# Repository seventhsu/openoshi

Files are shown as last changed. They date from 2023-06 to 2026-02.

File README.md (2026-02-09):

# OpenOshi
A fully open-source, DIY concert penlight. (v2.0)

Whether in the midst of the crowd at Belluna Dome or sitting in the dark in your bedroom, cheer on your favorite idols with this powerful, fully customizable penlight. It runs off of a single lithium battery and charges via USB-C to shine bright for hours of your favorite performances.

Best of all, it costs **less than $10 to make!** Total! That includes the PCB, the components, the battery, and the handle and tube! All while being fully hackable and modifiable. Manufacture in quantity and see how many you can hold in one hand: a classic idolfan challenge. 

This project consists of:
- a 3D-printable handle and screw-in translucent blade
- the Lightboard: a central PCB with an RGBW LED, a CH32V003F4U6 microcontroller, buttons and a USB-C charging port
- software to easily add your favorite idols' colors to your Lightboard

OpenOshi's electrical and mechanical components are open-source hardware licensed under CERN-OHL-S-2.0 (see the root `LICENSE` file). The firmware is open-source software licensed under the MIT License (see `firmware/LICENSE`). The `ch32fun` SDK included as a submodule of the firmware remains under its own MIT License; refer to the submodule's `LICENSE` file.

**Building tips**
- For printing the handle, I suggest a neutral color of PLA filament, and for the tube, transparent PETG printed at 100% rectilinear infill.
- The PCB is made to JLCPCB 2-layer specifications and tolerances as of July 2025. Modify if needed to meet your preferred PCB supplier's capabilities.
- The control firmware can be flashed to the board with a single wire using the SWIO programming pad on the top. To do so, you will need a WCH-Link programmer or equivalent and a flashing tool; [`ch32fun`](https://github.com/cnlohr/ch32fun) names several good open-source options like the `esp32s2-funprog` for the former, and it implements the `minichlink` tool for the latter.

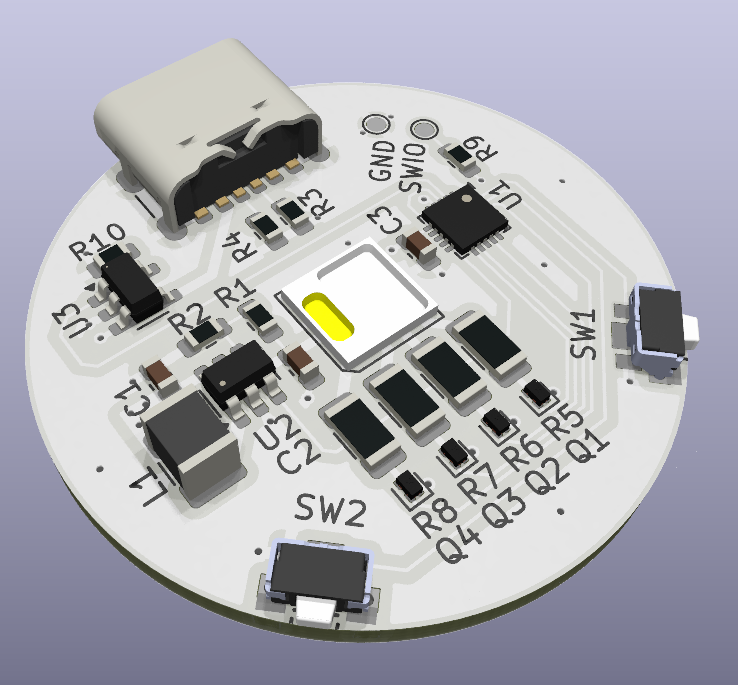
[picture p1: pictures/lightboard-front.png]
Lightboard top side

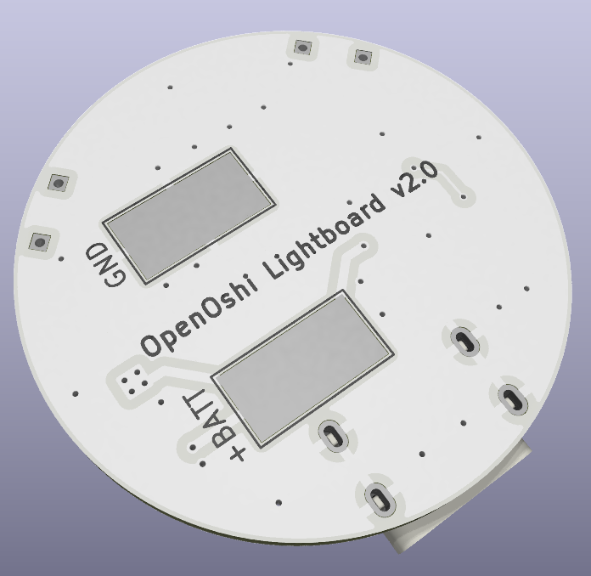
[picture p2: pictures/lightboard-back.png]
Lightboard bottom side


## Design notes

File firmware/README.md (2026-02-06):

# OpenOshi CH32V003 firmware

To pull the `ch32fun` SDK and compile `minichlink`, the flasher tool:
```bash
git submodule update --init --recursive
cd ch32fun/minichlink
make
```

To build the board firmware, creating images and build artifacts in `src/`:
```bash
make -C src
```

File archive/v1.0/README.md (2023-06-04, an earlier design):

# OpenOshi
A fully open-source, DIY idol concert lightstick. (v1.0)

Whether in the midst of the crowd at Belluna Dome or sitting in the dark in your bedroom, cheer on your favorite idols with this powerful, fully customizable lightstick. Designed in the image of the King Blade X10, ubiquitous in Japan, this lightstick runs off of a single lithium-ion battery to shine bright for hours of your favorite performances.

OpenOshi is fully DIY. It consists of:
- a 3D-printable handle and screw-in translucent blade
- a central PCB with an RGBW LED
- a simple board programming interface to add your favorite idols' colors

OpenOshi is open-source; all are free to modify it to their liking or submit improvements.

**Building tips**
- For the handle and cap, I suggest a neutral color of PLA filament, and for the tube, transparent PETG printed at 100% rectilinear infill.
- The PCB is made to OSH Park specifications and tolerances as of June 2023. Modify as needed to meet your preferred PCB supplier's capabilities.
- Control software written in AVR C is provided, and can be compiled and flashed to the board using the 6-pin ICSP port at the bottom.
- The handle was originally designed with a single lithium-ion battery as a power source in mind, so there is a cutout in the bottom of the handle for a common TP4056 USB-C lithium-ion charger. However, the board can also be powered by three alkaline batteries (such as AAAs) in series for 4.5V, so the cutout can be patched up if deemed unnecessary.




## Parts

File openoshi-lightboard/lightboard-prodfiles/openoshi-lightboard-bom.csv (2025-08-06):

Comment | Designator | Footprint | LCSC Part Number
10u | C1,C2 | Capacitor_SMD:C_0603_1608Metric | C19702
0.1u | C3 | Capacitor_SMD:C_0603_1608Metric | C14663
USB_C_Receptacle_PowerOnly_6P | J1 | Connector_USB:USB_C_Receptacle_GCT_USB4125-xx-x_6P_TopMnt_Horizontal | C456012
4.7uH | L1 | Inductor_SMD:L_1210_3225Metric | C703083
PMZ600UNE | Q1,Q2,Q3,Q4 | Package_TO_SOT_SMD:SOT-883 | C547286
1Meg | R1 | Resistor_SMD:R_0603_1608Metric | C105578
127K | R2 | Resistor_SMD:R_0603_1608Metric | C245905
5.1K | R3,R4 | Resistor_SMD:R_0603_1608Metric | C105580
12.7 | R5,R8 | Resistor_SMD:R_1206_3216Metric | C870404
20 | R6 | Resistor_SMD:R_1206_3216Metric | C114941
11.3 | R7 | Resistor_SMD:R_1206_3216Metric | C870385
220 | R9 | Resistor_SMD:R_0603_1608Metric | C107696
2K | R10 | Resistor_SMD:R_0603_1608Metric | C105576
AKE31A | SW1,SW2 | openoshi-lightboard:SW_EVP-AKE31A_PAN | C569760
CH32V003FxUx | U1 | Package_DFN_QFN:QFN-20-1EP_3x3mm_P0.4mm_EP1.65x1.65mm | C5299908
TLV61070A | U2 | Package_TO_SOT_SMD:SOT-23-6 | C6881375
TP4054 | U3 | Package_TO_SOT_SMD:SOT-23-5 | C668215

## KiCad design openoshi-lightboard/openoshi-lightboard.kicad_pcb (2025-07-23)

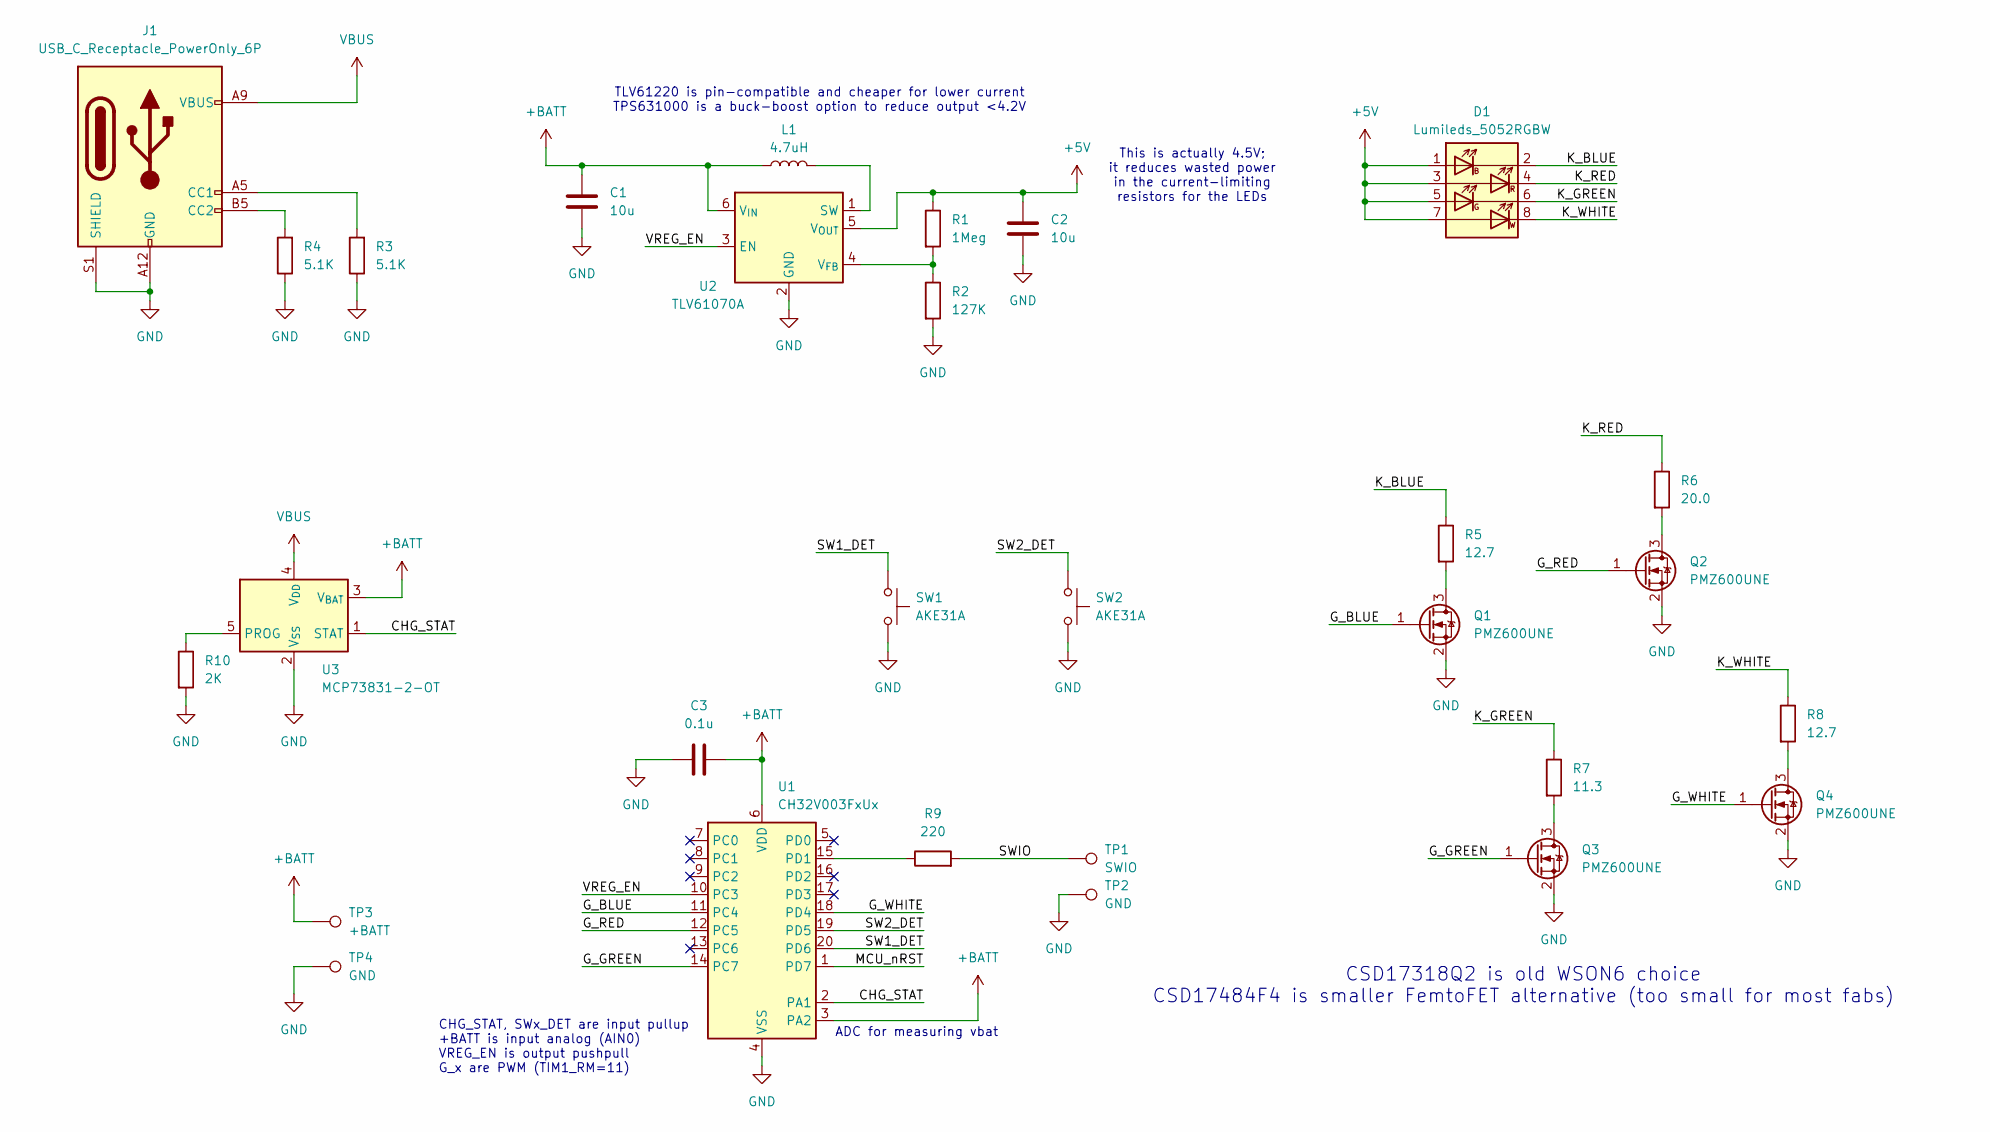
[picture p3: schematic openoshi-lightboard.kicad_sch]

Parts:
C1, C2: 10u; C_0603_1608Metric
C3: 0.1u; C_0603_1608Metric
D1: Lumileds_5052RGBW; LED_Lumileds_5052RGBW_LGA9_5.0x5.2mm_P0.5mm
J1: USB_C_Receptacle_PowerOnly_6P; USB_C_Receptacle_GCT_USB4125-xx-x_6P_TopMnt_Horizontal
L1: 4.7uH; L_1210_3225Metric
Q1, Q2, Q3, Q4: PMZ600UNE; SOT-883
R1: 1Meg; R_0603_1608Metric
R2: 127K; R_0603_1608Metric
R3, R4: 5.1K; R_0603_1608Metric
R5, R8: 12.7; R_1206_3216Metric
R6: 20.0; R_1206_3216Metric
R7: 11.3; R_1206_3216Metric
R9: 220; R_0603_1608Metric
R10: 2K; R_0603_1608Metric
SW1, SW2: AKE31A; SW_EVP-AKE31A_PAN
TP1: SWIO; TestPoint_Pad_D1.0mm
TP2: GND; TestPoint_Pad_D1.0mm
TP3: +BATT; Battery_SolderPad
TP4: GND; Battery_SolderPad
U1: CH32V003FxUx; QFN-20-1EP_3x3mm_P0.4mm_EP1.65x1.65mm
U2: TLV61070A; SOT-23-6
U3: MCP73831-2-OT; SOT-23-5

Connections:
+5V: C2.1, D1.1 (AB), D1.3 (AR), D1.5 (AG), D1.7 (AW), D1.9 (AR), R1.1, U2.5 (V_{OUT})
+BATT: C1.1, C3.2, L1.1, TP3.1, U1.3 (PA2), U1.6 (VDD), U2.6 (V_{IN}), U3.3 (V_{BAT})
/CHG_STAT: U1.2 (PA1), U3.1 (STAT)
/G_BLUE: Q1.1 (G), U1.11 (PC4)
/G_GREEN: Q3.1 (G), U1.14 (PC7)
/G_RED: Q2.1 (G), U1.12 (PC5)
/G_WHITE: Q4.1 (G), U1.18 (PD4)
/K_BLUE: D1.2 (KB), R5.1
/K_GREEN: D1.6 (KG), R7.1
/K_RED: D1.4 (KR), R6.1
/K_WHITE: D1.8 (KW), R8.1
/MCU_nRST: U1.1 (PD7)
/SW1_DET: SW1.1, U1.20 (PD6)
/SW2_DET: SW2.1, U1.19 (PD5)
/SWIO: R9.2, TP1.1
/VREG_EN: U1.10 (PC3), U2.3 (EN)
GND: C1.2, C2.2, C3.1, J1.A12 (GND), J1.B12 (GND), J1.S1 (SHIELD), Q1.2 (S), Q2.2 (S), Q3.2 (S), Q4.2 (S), R2.2, R3.1, R4.1, R10.2, SW1.2, SW2.2, TP2.1, TP4.1, U1.4 (VSS), U1.21 (VSS), U2.2 (GND), U3.2 (V_{SS})
unnamed: J1.A5 (CC1), R3.2
unnamed: J1.B5 (CC2), R4.2
unnamed: Q1.3 (D), R5.2
unnamed: Q2.3 (D), R6.2
unnamed: Q3.3 (D), R7.2
unnamed: Q4.3 (D), R8.2
unnamed: R9.1, U1.15 (PD1)
unnamed: L1.2, U2.1 (SW)
unnamed: R1.2, R2.1, U2.4 (V_{FB})
unnamed: R10.1, U3.5 (PROG)
VBUS: J1.A9 (VBUS), J1.B9 (VBUS), U3.4 (V_{DD})

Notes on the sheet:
This is actually 4.5V; it reduces wasted power in the current-limiting resistors for the LEDs
CSD17318Q2 is old WSON6 choice CSD17484F4 is smaller FemtoFET alternative (too small for most fabs)
TLV61220 is pin-compatible and cheaper for lower current TPS631000 is a buck-boost option to reduce output <4.2V
CHG_STAT, SWx_DET are input pullup +BATT is input analog (AIN0) VREG_EN is output pushpull G_x are PWM (TIM1_RM=11)
ADC for measuring vbat

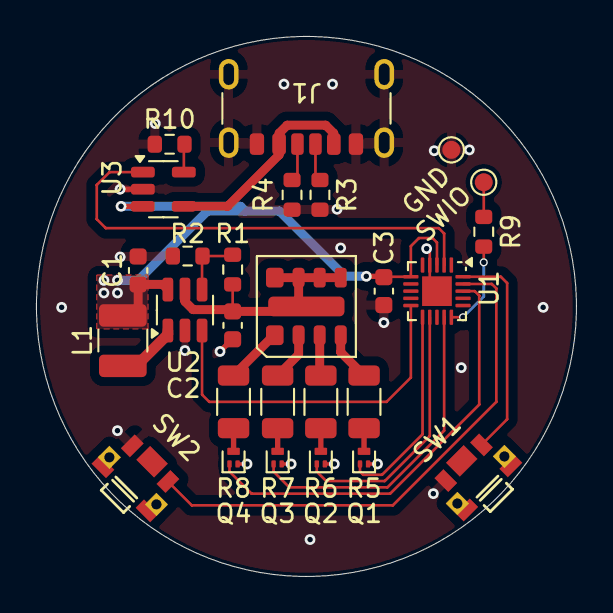
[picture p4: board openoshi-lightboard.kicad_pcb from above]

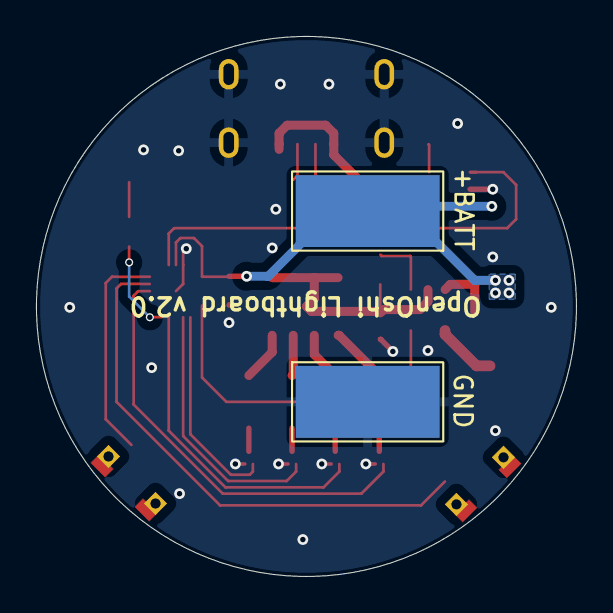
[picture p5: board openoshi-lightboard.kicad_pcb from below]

Board: 2 copper layers, 30.0 x 30.0 mm, 29 parts (2 on the bottom side), 27 nets.

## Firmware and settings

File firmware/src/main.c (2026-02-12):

// SPDX-License-Identifier: MIT
// Copyright (c) 2025-2026 Seventhsu

#include "../ch32fun/ch32fun/ch32fun.h"
#include <stdio.h>

#define PERIPH_CLOCK FUNCONF_SYSTEM_CORE_CLOCK  // HPRE=DIV1 after SystemInit

#define LED_PWM_MAX_FREQ_HZ 1000 // Change me at your leisure!
#define COLOR_BIT_DEPTH 8

#define NUM_COLORS     (sizeof(colorTable) / sizeof(colorTable[0]))
#define DEBOUNCE_MS    30
#define LONG_PRESS_MS  800
#define POLL_MS        10

// colorTable[i][0:3] represent B, G, R, W channels of one color setting
uint8_t colorTable[][4] = {
	{0x0,	0x0,	0xff,	0x0},   // Color red
    {0x0,	0xff,	0xff,	0x0},   // Color yellow
	{0x0,	0xff,	0x0,	0x0},   // Color green
    {0xff,	0xff,	0x0,	0x0},   // Color cyan
	{0xff,	0x0,	0x0,	0x0},   // Color blue
    {0xff,	0x0,	0xff,	0x0},   // Color magenta
	{0x0,	0x0,	0x0,	0xff},  // Color white
};

// The color the penlight should display if it was on (index into colorTable)
static volatile int currColor;

// Bitmask set by ISR: bit 0 = SW1 (PD6), bit 1 = SW2 (PD5)
static volatile uint8_t btnEvent;

void EXTI7_0_IRQHandler(void) __attribute__((interrupt));
void EXTI7_0_IRQHandler(void) {
    if (EXTI->INTFR & EXTI_Line6)  btnEvent |= 0x01;  // SW1
    if (EXTI->INTFR & EXTI_Line5)  btnEvent |= 0x02;  // SW2
    EXTI->INTFR = EXTI_Line6 | EXTI_Line5;          // Acknowledge both
}

void tim1PwmInit(void) {
    RCC->APB2PCENR |= RCC_APB2Periph_TIM1;

    // Map and AF-configure pins to be used by TIM1
    // TIM1 map: CH1=PC4(blue), CH2=PC7(green), CH3=PC5(red), CH4=PD4(white)
    AFIO->PCFR1 |= AFIO_PCFR1_TIM1_REMAP_FULLREMAP;
    funPinMode(PC4, GPIO_CFGLR_OUT_2Mhz_AF_PP); // blue LED
    funPinMode(PC7, GPIO_CFGLR_OUT_2Mhz_AF_PP); // green LED
    funPinMode(PC5, GPIO_CFGLR_OUT_2Mhz_AF_PP); // red LED
    funPinMode(PD4, GPIO_CFGLR_OUT_2Mhz_AF_PP); // white LED

    // Reset TIM1 to init all regs
    RCC->APB2PRSTR |= RCC_APB2Periph_TIM1;
	RCC->APB2PRSTR &= ~RCC_APB2Periph_TIM1;

    /* Yes, the colors could have better than 8-bit depth
     * if the prescaler was set to 0 and autoreload was larger.
     * But 8-bit color is well-documented and easy to work with.
     */
    // Autoreload (PWM period) is set so that 8-bit duty cycle values match its range
    // PSC is calculated such that the actual PWM freq is <= LED_PWM_MAX_FREQ_HZ
    const uint32_t autoreload = (1<<COLOR_BIT_DEPTH) - 1; // 255
    TIM1->PSC = (PERIPH_CLOCK / (LED_PWM_MAX_FREQ_HZ * (autoreload + 1)));
    TIM1->ATRLR = autoreload;

    // Set mode = b110 (PWM mode 1, left aligned) and enable shadow regs ("preload") for all
    TIM1->CHCTLR1 |= TIM_OC2M_2 | TIM_OC2M_1 | TIM_OC2PE | TIM_OC1M_2 | TIM_OC1M_1 | TIM_OC1PE;
    TIM1->CHCTLR2 |= TIM_OC4M_2 | TIM_OC4M_1 | TIM_OC4PE | TIM_OC3M_2 | TIM_OC3M_1 | TIM_OC3PE;

    // CTLR1 defaults to up-count, UEVs generated (auto-copy from shadow reg), edge align
	TIM1->CTLR1 |= TIM_ARPE; // enable auto-reload of preload

    TIM1->CCER |= TIM_CC4E | TIM_CC3E | TIM_CC2E | TIM_CC1E; // All channels output enable

    // Kickstart the counter with a UG bit set
    TIM1->SWEVGR |= TIM_UG;
    TIM1->CTLR1 |= TIM_CEN;
    TIM1->BDTR |= TIM_MOE; // Main Output Enable required for advanced timer TIM1
}

void updateColor(void) {
    TIM1->CH1CVR = (uint32_t) colorTable[currColor][0];
    TIM1->CH2CVR = (uint32_t) colorTable[currColor][1];
    TIM1->CH3CVR = (uint32_t) colorTable[currColor][2];
    TIM1->CH4CVR = (uint32_t) colorTable[currColor][3];
}

void extiInit(void) {
    // Map PD5 -> EXTI5, PD6 -> EXTI6
    AFIO->EXTICR |= AFIO_EXTICR_EXTI5_PD | AFIO_EXTICR_EXTI6_PD;

    // Enable interrupt (for WFI wake) and event (for WFE wake) on lines 5 and 6
    EXTI->INTENR |= EXTI_INTENR_MR5 | EXTI_INTENR_MR6;
    EXTI->EVENR  |= EXTI_EVENR_MR5  | EXTI_EVENR_MR6;

    // Falling edge trigger (buttons are active-low with pull-ups)
    EXTI->FTENR  |= EXTI_FTENR_TR5  | EXTI_FTENR_TR6;

    NVIC_EnableIRQ(EXTI7_0_IRQn);
}

void enterStandby(void) {
    // Turn off LED outputs
    TIM1->CH1CVR = 0; TIM1->CH2CVR = 0;
    TIM1->CH3CVR = 0; TIM1->CH4CVR = 0;

    // Disable boost converter
    funDigitalWrite(PC3, FUN_LOW);

    // Configure for standby wake
    RCC->APB1PCENR |= RCC_APB1Periph_PWR;
    PWR->CTLR |= PWR_CTLR_PDDS;
    PFIC->SCTLR |= (1 << 2); // SLEEPDEEP

    // Wait for button release before sleeping (avoid instant wake)
    while (funDigitalRead(PD6) == 0 || funDigitalRead(PD5) == 0)
        Delay_Ms(10);
    Delay_Ms(DEBOUNCE_MS);

    // Clear any pending EXTI events
    EXTI->INTFR = EXTI_Line6 | EXTI_Line5;

    // Enter deep standby (WFE)
    __WFE();
}

void exitStandby(void) {
    SystemInit();                       // Restore PLL and clocks
    PFIC->SCTLR &= ~(1 << 2);           // Clear SLEEPDEEP for WFI mode
    funDigitalWrite(PC3, FUN_HIGH);     // Re-enable boost converter
    Delay_Ms(5);                        // Let boost converter stabilize
    updateColor();                      // Restore saved color to PWM

    // Debounce the wake button press
    while (funDigitalRead(PD6) == 0 || funDigitalRead(PD5) == 0)
        Delay_Ms(10);
    Delay_Ms(DEBOUNCE_MS);
    btnEvent = 0;                       // Clear any events from the wake press
}

uint16_t readBatteryMv(void) {
    // Enable internal Vrefint on ADC channel 8
    ADC1->CTLR2 |= ADC_TSVREFE;

    // Read internal 1.2V reference (channel 8)
    uint16_t vref_raw = funAnalogRead(ADC_Channel_Vrefint);

    // Disable Vrefint to save power
    ADC1->CTLR2 &= ~ADC_TSVREFE;

    // VDD = Vrefint_known * ADC_max / vref_raw
    // In mV: (1200 * 1023) / vref_raw
    if (vref_raw == 0) return 0; // Guard against division by zero
    return (uint16_t)((1200UL * 1023) / vref_raw);
}

int main(void) {
    SystemInit();
    Delay_Ms(5000); // Reprogramming window: allow reflashing before sleep

    funGpioInitAll(); // Enables AFIO + ports A C D

    tim1PwmInit();
    funAnalogInit(); // Initialize ADC via ch32fun helper

    // Assign directions to general-purpose pins
    funPinMode(PA1, GPIO_CFGLR_IN_PUPD);        // batt CHG_STAT
    //funPinMode(PA2, GPIO_CFGLR_IN_ANALOG);      // vbatt adc, on AIN0
    funPinMode(PC3, GPIO_CFGLR_OUT_2Mhz_PP);    // VREG_EN
    funPinMode(PD6, GPIO_CFGLR_IN_PUPD);        // SW1
    funPinMode(PD5, GPIO_CFGLR_IN_PUPD);        // SW2
    // Explicitly enable input-pullup resistors for SWy by writing to GPIOx_OUTDR
    funDigitalWrite(PD6, FUN_HIGH);
    funDigitalWrite(PD5, FUN_HIGH);

    // Configure EXTI for button interrupts and events
    extiInit();

    // Write timer duty cycles to display first color
    currColor = 0;
    updateColor();

    // Enable power supply by asserting VREG_EN, thus turning on the LED
    funDigitalWrite(PC3, FUN_HIGH);

    while (1) {
        // WFI in loop ensures mcu always goes to sleep when not doing anything
        __WFI(); // Wait For (button) Interrupt

        /*
         * At this point the light is active and the mcu can sleep. The button interrupts
         * wake the mcu from WFI, and their ISRs simply set a flag and return execution to
         * the loop code below. This code reads the flag, debounces the button, and if
         * short-pressed, sends a new color to TIM1 and reenters sleep. If long-pressed (user
         * wants to turn off the device), it should disable the light and the boost conv,
         * then WFE (standby).
         */
        
        if (!btnEvent) continue; // Spurious wake
        uint8_t btn = btnEvent;
        btnEvent = 0;

        // Software debounce
        Delay_Ms(DEBOUNCE_MS);

        // Determine which pin to poll (pick first if both pressed)
        uint8_t pin = (btn & 0x01) ? PD6 : PD5;

        if (funDigitalRead(pin) != 0) continue; // Bounced away, ignore

        // Long press detection: poll until release or timeout
        uint16_t held = DEBOUNCE_MS;
        while (funDigitalRead(pin) == 0 && held < LONG_PRESS_MS) {
            Delay_Ms(POLL_MS);
            held += POLL_MS;
        }

        if (held >= LONG_PRESS_MS) {
            // LONG PRESS: transition to LED_OFF (standby)
            enterStandby();
            // Execution resumes here after WFE wake
            exitStandby();
        } else {
            // SHORT PRESS: cycle color
            if (btn & 0x01) {
                currColor = (currColor + 1) % NUM_COLORS; // SW1: forward
            } else {
                currColor = (currColor + NUM_COLORS - 1) % NUM_COLORS; // SW2: backward
            }
            updateColor();
        }
    }
    return 0;
}

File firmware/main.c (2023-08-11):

/*
 * LightstickSoftware.c
 *
 * Created: 6/22/2023 9:30:34 PM
 * Author : alial
 */

#ifndef F_CPU
#define F_CPU 8000000UL
#endif //F_CPU

#include <avr/io.h>
#include <util/delay.h>
#include <avr/interrupt.h>

// THESE ARE FOR PORT B
#define bitmask_G 0b00000010 // Green channel is on TIM1A, PORTB1
#define bitmask_W 0b00000100 // White channel is on TIM1B, PORTB2
// THESE ARE FOR PORT D
#define bitmask_R 0b00000001 // Red channel is on TIM3A, PORTD0
#define bitmask_B 0b00000100 // Blue channel is on TIM3B, PORTD2

uint16_t colortable[][4] = {
	{0x1ff,	0x0,	0x0,	0x0},
	{0x0,	0x1ff,	0x0,	0x0},
	{0x0,	0x0,	0x1ff,	0x0},
	{0x0,	0x0,	0x0,	0x1ff}
};


// Interrupt subroutine for the button debouncer's 1ms timer
ISR(TIMER0_COMPA_vect) {
	// Do garbage here
}


int main(void)
{
	// Set GPIO direction for the 4 PWM channels
	DDRB |= (bitmask_G | bitmask_W);
	DDRD |= (bitmask_R | bitmask_B);

	// test
	PORTD |= (bitmask_B);

	// Enables interrupts globally by setting the I-bit of SREG
	sei();
	
	uint16_t dutycycle_R, dutycycle_G, dutycycle_B, dutycycle_W;
	// Set thresholds here from a list of colors and button toggling
	dutycycle_R = 0x0ff;
	dutycycle_G = 0x0;
	dutycycle_B = 0x1ff;
	dutycycle_W = 0x0;
	
	// Update the PWM generators with the new threshold
	OCR1A = dutycycle_G;
	OCR1B = dutycycle_W;
	OCR3A = dutycycle_R;
	OCR3B = dutycycle_B;
	
	// Set some data control registers.
	// COMn[1:0] = 2'b10, for "normal" PWM that widens with a larger dutycycle value
	// WGMn[3:0] = 4'b1110, for fast mode PWM with the counter's max value in ICRn
	// CSn[2:0] = 3'b001, to clock directly from clkio (no prescaler)
	// ICRn = 0x0fff, as our counter top, to create 12-bit PWM timer resolution
	TCCR1A |= (0b10 << COM1A0) | (0b10 << COM1B0) | (0b10 << WGM10);
	ICR1 = 0x0fff;
	TCCR1B |= (0b11 << WGM12) | (0b001 << CS10);
	TCCR3A |= (0b10 << COM3A0) | (0b10 << COM3B0) | (0b10 << WGM30);
	ICR3 = 0x0fff;
	TCCR3B |= (0b11 << WGM32) | (0b001 << CS30);
	
	// TIM0A makes an internal 1ms interrupt clock for switch debounce
	// clkio is 8 MHz, so clkio/64 and 125 counts gives us a perfect 1ms timer
	// WGM0[2:0] = 3'b010, for CTC (Clear Timer on Compare match) mode
	// CS0[2:0] = 3'b011, for clkio/64
	// Set OCIE0A to trigger an interrupt every time the compare matches
	OCR0A = 125;
	TIMSK0 |= (1 << OCIE0A);
	TCCR0A |= (0b10 << WGM00);
	TCCR0B |= (0b0 << WGM02) | (0b011 << CS00);

	// Forever loop here.
	while (1) {
		// abc
	}
}

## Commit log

2023-06-03 Moved gerbars into lightboard-gerbers/
    [pcb1.gbo, pcb1.gbp, pcb1.gbs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]
2025-04-22 work on v2.0 has begun
    [openoshi-lightboard.kicad_pcb, openoshi-lightboard.kicad_sch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]
2025-04-27 added pictures to readme
    [openoshi-lightboard.kicad_pcb]
2025-04-29 updated readme and part names
    [openoshi-lightboard.kicad_pcb, openoshi-lightboard.kicad_sch]
2025-05-14 added LED
    [openoshi-lightboard.kicad_pcb, openoshi-lightboard.kicad_sch]
2025-06-23 Safety upgrades all around
    [openoshi-lightboard.kicad_pcb, openoshi-lightboard.kicad_sch]
2025-07-09 Tentative sch completion, initial layout
    [openoshi-lightboard.kicad_pcb, openoshi-lightboard.kicad_sch]
2025-07-19 Prepping for large reroute
    [openoshi-lightboard.kicad_pcb]
2025-07-22 Reroute complete
    [openoshi-lightboard.kicad_pcb, openoshi-lightboard.kicad_sch]
2025-07-23 Assembly files created, first run
    [openoshi-lightboard-B_Cu.gbr, openoshi-lightboard-B_Mask.gbr, openoshi-lightboard-B_Paste.gbr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]
2025-08-06 Begin firmware work
    [openoshi-lightboard-bom.csv, openoshi-lightboard.kicad_sch]
2025-09-14 more progress on pin cfg
2025-09-15 Completed ledpwm code
2026-02-07 Implement WFE, buttons irq and debounce
2026-02-07 Dredged up and archived v1.0 assets
    [pcb1.gbl, pcb1.gbo, pcb1.gbp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]
